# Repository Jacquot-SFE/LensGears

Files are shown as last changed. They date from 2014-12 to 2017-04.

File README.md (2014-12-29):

Laser Cut Lens Gears
==================

*NOTE: all of this work is preliminary.  Nothing here has been completed or tested.*

Resources for laser cut lens gears, starting with .8 pitch, but the sky is the limits. 

### Inkscape notes

There's a gear generator in *extensions->render->gear*.
The magic number for circular pitch is 8.835 px. (see notebook on 3/24/2014).

If you were really on top of things, you'd generate a path that traces around the outside of gear, so that the laser kerf skirted the outer edge of the gear.

Repository Contents
-------------------
* **/DesignFiles** - SVG files for the gears.  
* **/Notes** - Other relevant information.

License Information
-------------------

All contents of this repository are released under [Creative Commons Share-alike 3.0](http://creativecommons.org/licenses/by-sa/3.0/).

Author: Byron Jacquot@ SparkFun Electonics

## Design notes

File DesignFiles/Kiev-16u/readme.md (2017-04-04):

Kiev 16u Lenses
--

If you're shooting with a Blackmagic Pocket camera, you've probably heard about the lenses from the Kiev 16U, a Russian (well, Ukranian...when the cameras were made, Ukraine was part of the USSR) 16MM camera.  They come with a 3-slot turret, loaded with 3 prime lenses.

Unlike Bolex H16's, where the turret may be loaded with any number of lenses, Kiev 16Us all come with the same set of 3:

* MIR-11M 12mm/2
* VEGA-7-1M 20mm/2
* Tair-41M 50mm/2

A little googling will lead you to a bunch of reviews and test footage.  The 12mm is a touch dark in the corners.  The 50mm is a really nice lens (though on a 16mm frame, 50mm is telephoto), with a many-bladed iris, with a nearly round opening, for nice, circular bokeh.

The most likely source for these lenses is EBay.

You'll also need an MFT adapter.  They're machined by RAFCamera, and run about $50.  I bought my set of lenses from him, including the adataper.  Shipped from Belarus in about a week.

If you're shopping, a couple things to note:

* The "-M" suffix is for the Kiev 16u lenses.  The same lenses are also around in the Krasnogorsk Bayonet mount, taking a completely different adapter, and having F/2.2 apertures.  Look carefully for the threads in the pictures - they're usually kinda brassy 
   
## Gears

The files here were done for my lenses.  They may need adjustment for your own lenses.

Apparently these were in production for a long time, and there are some differences over their lifetime.  My lenses are "Zebra" style, with exposed, shiny aluminum rectangles on the aperture and focus rings.  I've also seen some all black versions, usually coming from Poland.

The OD of each gear is the same: 2.564"

The ID I measures on each focus ring:

* 12mm: 44.3mm 
* 20mm: 44.44mm
* 50mm #1: 46 (+/- 0.1)  not entirely round?  45.9 to 46.05
* 50mm #2: 46 (+/- 0.1)  not entirely round?  45.9 to 46.05

## Notes on cutting

First gears were cut from clear acrylic, for the 20mm.

ID set to 44.44 caused actual ID (allowing for kerf?) to be more like 44.7mm.  Adjusting downward by a bit, to 44.1mm, seems to fit better.  Same gear is fitting the 12mm and 20mm.

Cutter adjustments: Was doing 3 passes.  First 2 at 10 % speed, 100% power, 5000 Hz.  With those, the ID hole was cut, but teeth were still stuck.  3rd pass of just the teeth, raised to 25% speed, cut it nicely.

Only limited luck with black delrin yet.  Best results:
3.3mm black delrin, 20 % speed, 100% power, 500 Hz.  4 passes.
One issue is that the material warps as it heats up.  Another issue is that it wants to burn if the laser moves too slow, making the warping even worse.

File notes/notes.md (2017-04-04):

Notes On Designing Lens Gears
====

I'm using Inkscape for the lens gear design.  It has a gear generator tool that helps a bit.  It's not so helpful in a few regards, too.

* It's calibrated in pixels, 90 to the inch.  
* Not all programs agree on the pixel density, so transporting files may be problematic.  I think Corel uses 96 pix per inch.  
* The gear generator is also calibrated in pixels.

Gear generator is in Extensions->render->gear.
Set it as follows

* Teeth to fit diameter.
	* 80 teeth makes 2.5" pitch diameter
	* 100 teeth makes 3.125" pitch diameter
	* 128 teeth makes 4" PD.
* 8.835 pitch
* 20 degree pressure angle

I've been verifying some of my gear dimensions against  [Actobotics Gears](http://www.servocity.com/html/32_pitch_hub_gears__1__bore_.html).

## Gear Background

0.8 pitch is equivalent to 32 pitch.

32 pitch means 32 teeth on a 1" PD gear.  Thus 64 teeth is 2", 128 is 4"

Pitch diameter is the effective size of the gear, the average between the high and low spots of the teeth, or the size of an equivalent smooth wheel.  Outside diameter (OD) is a tiny bit larger.

## Lens Info

[mir.com.my](mir.com.my) has a bunch of information about old lenses, sometimes including mechanical drawings.  

### Specific Lenses

#### Nikon

I've mainly got Nikon/Nikkor glass, so that's what I can measure.

##### Nikkor-N 24mm f/2.8

Measures 2.5455" across widest part of focus ring (approx 64.6557 mm).

[](http://www.mir.com.my/rb/photography/companies/nikon/nikkoresources/6070nikkor/wides/24mmf28.pdf)

##### Nikkor-S 50mm f/1.4

Measures 67.10 mm across widest, fluted, part of focus ring.  That area is about 6mm deep, and there are 12 large flutes total, each mesa of the flutes has 10 little flutes.  Focus ruing moves forward by about 4mm as turned.

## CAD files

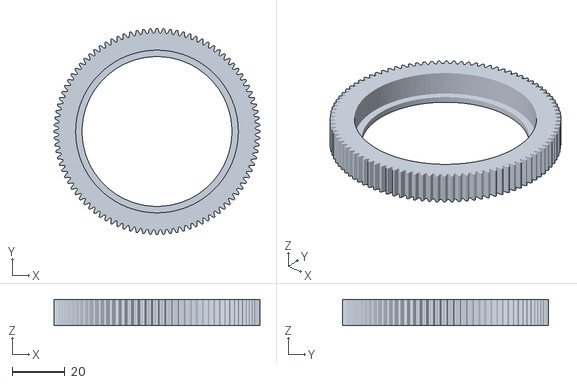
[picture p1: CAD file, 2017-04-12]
3d-design-files/35mm-E.stl
78.4 x 78.4 x 10.0

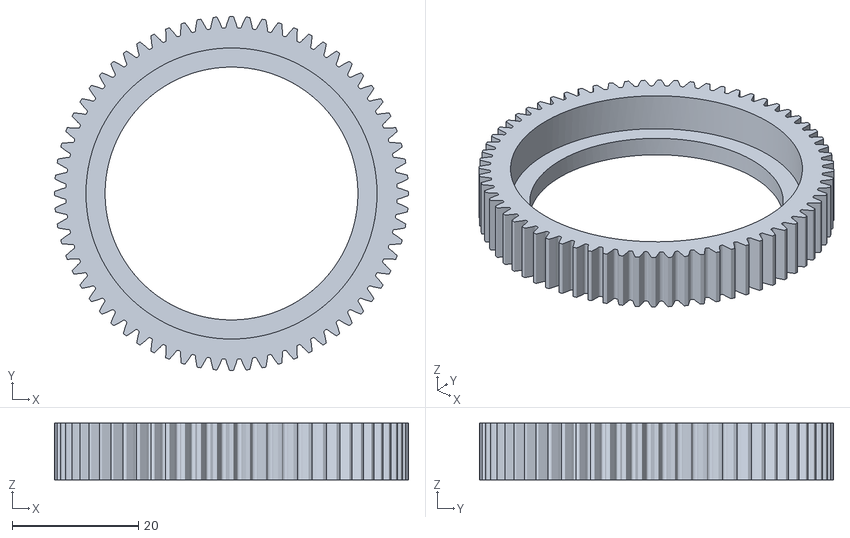
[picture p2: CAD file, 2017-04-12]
3d-design-files/50mm-tair41m-675817.stl
56.0 x 56.0 x 9.00

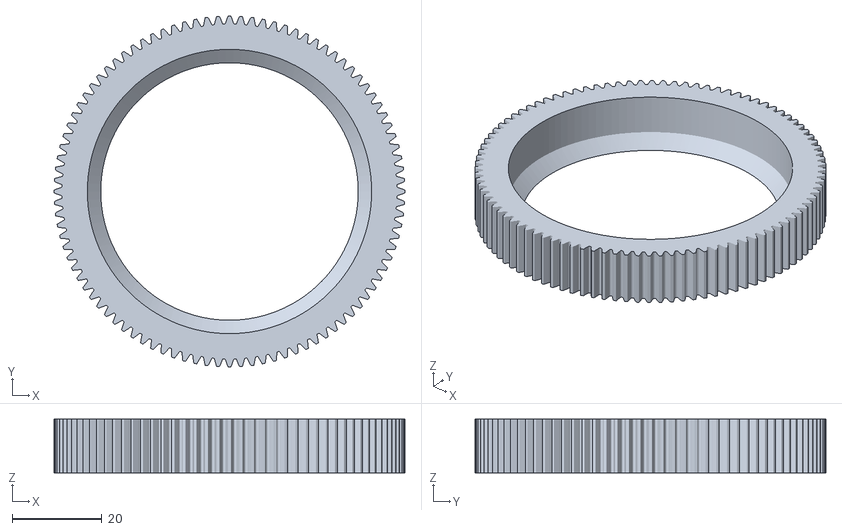
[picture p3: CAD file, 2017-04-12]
3d-design-files/28mm-rexagon.stl
78.4 x 78.4 x 12.0

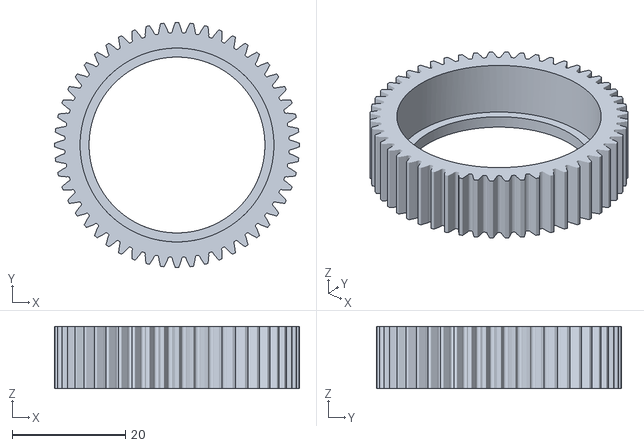
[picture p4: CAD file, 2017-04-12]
3d-design-files/izukar-16mm-take2.stl
43.2 x 43.2 x 11.0

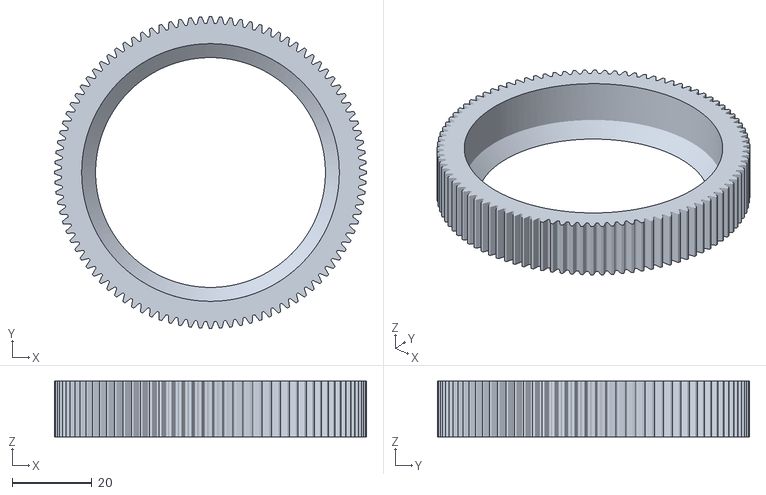
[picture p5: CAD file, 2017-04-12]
3d-design-files/24mm-N.stl
78.4 x 78.4 x 14.0

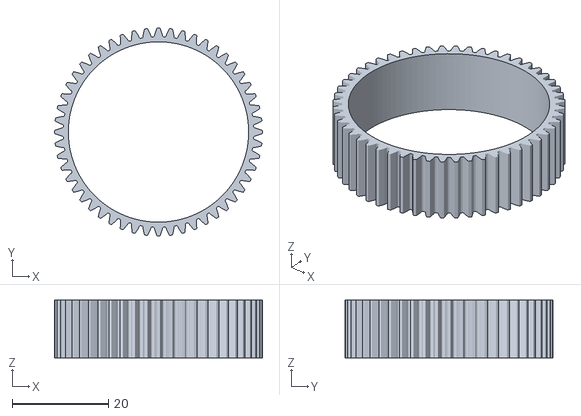
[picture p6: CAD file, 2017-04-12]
3d-design-files/izukar-16mm.stl
43.2 x 43.2 x 12.0

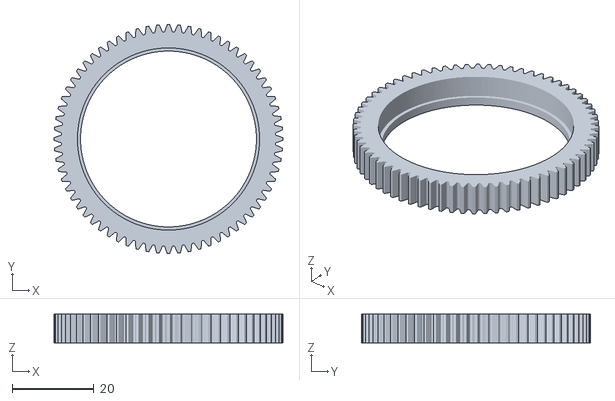
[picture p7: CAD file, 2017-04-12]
3d-design-files/12mm-mir11-701172.stl
56.0 x 56.0 x 7.00

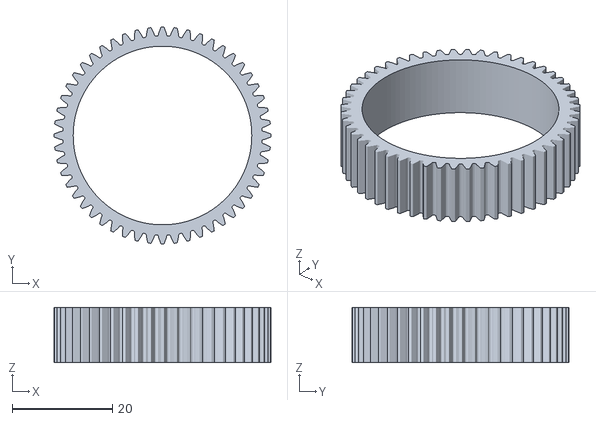
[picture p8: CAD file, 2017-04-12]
3d-design-files/fujian-25mm.stl
43.2 x 43.2 x 11.0

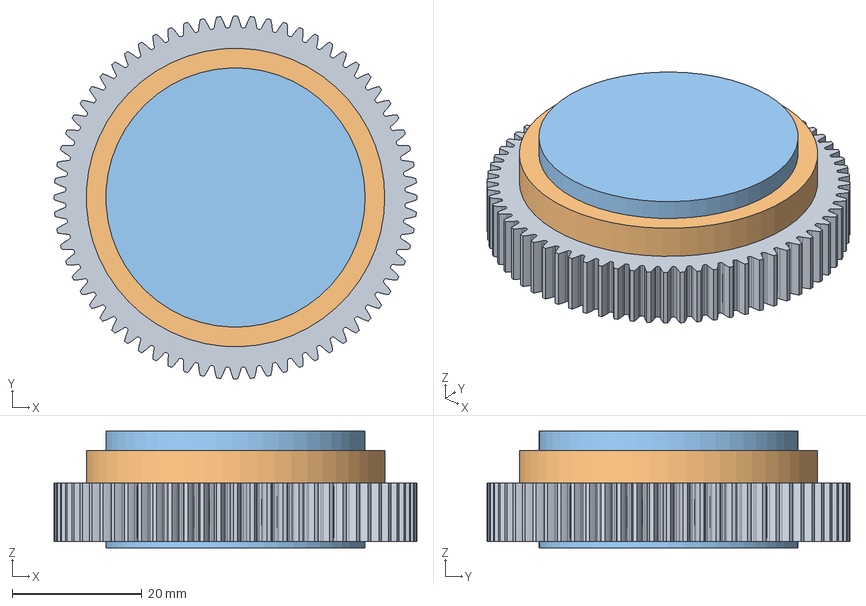
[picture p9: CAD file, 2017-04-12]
3d-design-files/parametric-model-kiev.FCStd
56.0 x 56.0 x 18.0 mm

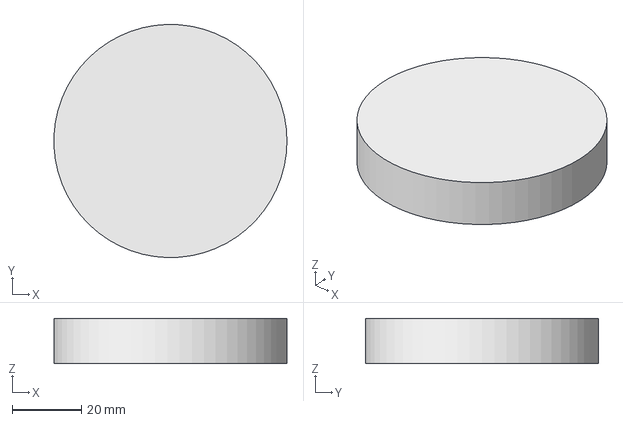
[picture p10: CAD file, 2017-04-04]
3d-design-files/parametric-model.FCStd
67.1 x 67.1 x 13.0 mm

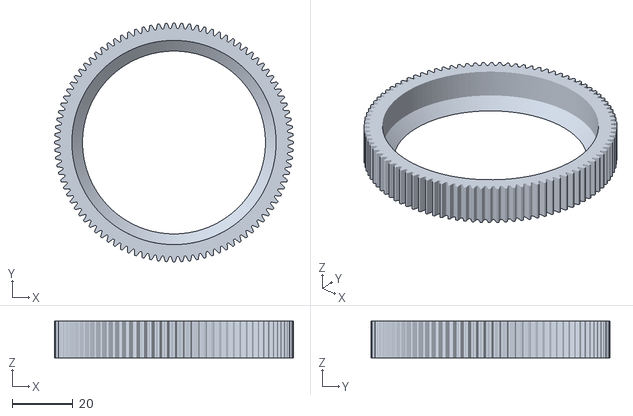
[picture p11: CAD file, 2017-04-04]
3d-design-files/50mm-S.stl
78.4 x 78.4 x 12.0

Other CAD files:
3d-design-files/20mm-beta-7-1-700594.stl
3d-design-files/p-model-rexagon.FCStd
3d-design-files/parametric-model-nikon-e.FCStd
3d-design-files/p-model-smaller.FCStd
3d-design-files/50mm-SC.stl

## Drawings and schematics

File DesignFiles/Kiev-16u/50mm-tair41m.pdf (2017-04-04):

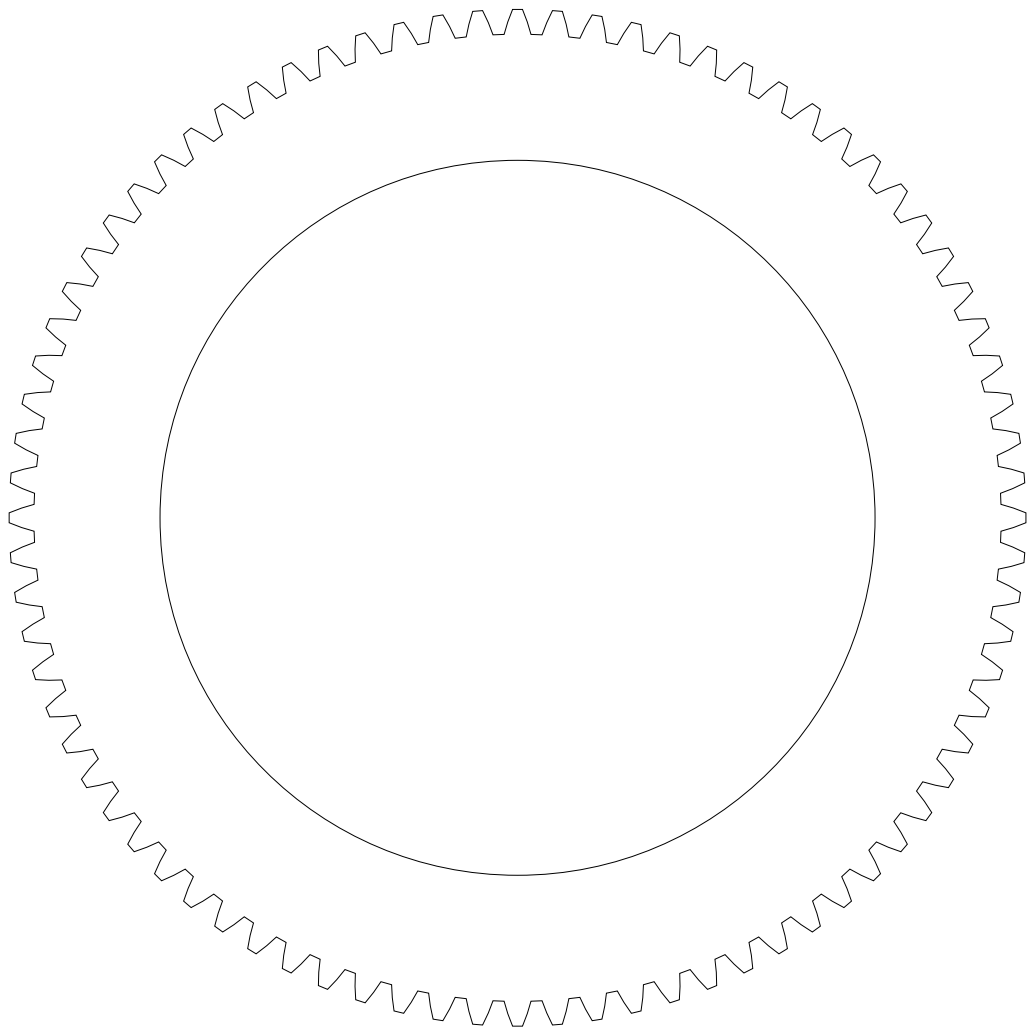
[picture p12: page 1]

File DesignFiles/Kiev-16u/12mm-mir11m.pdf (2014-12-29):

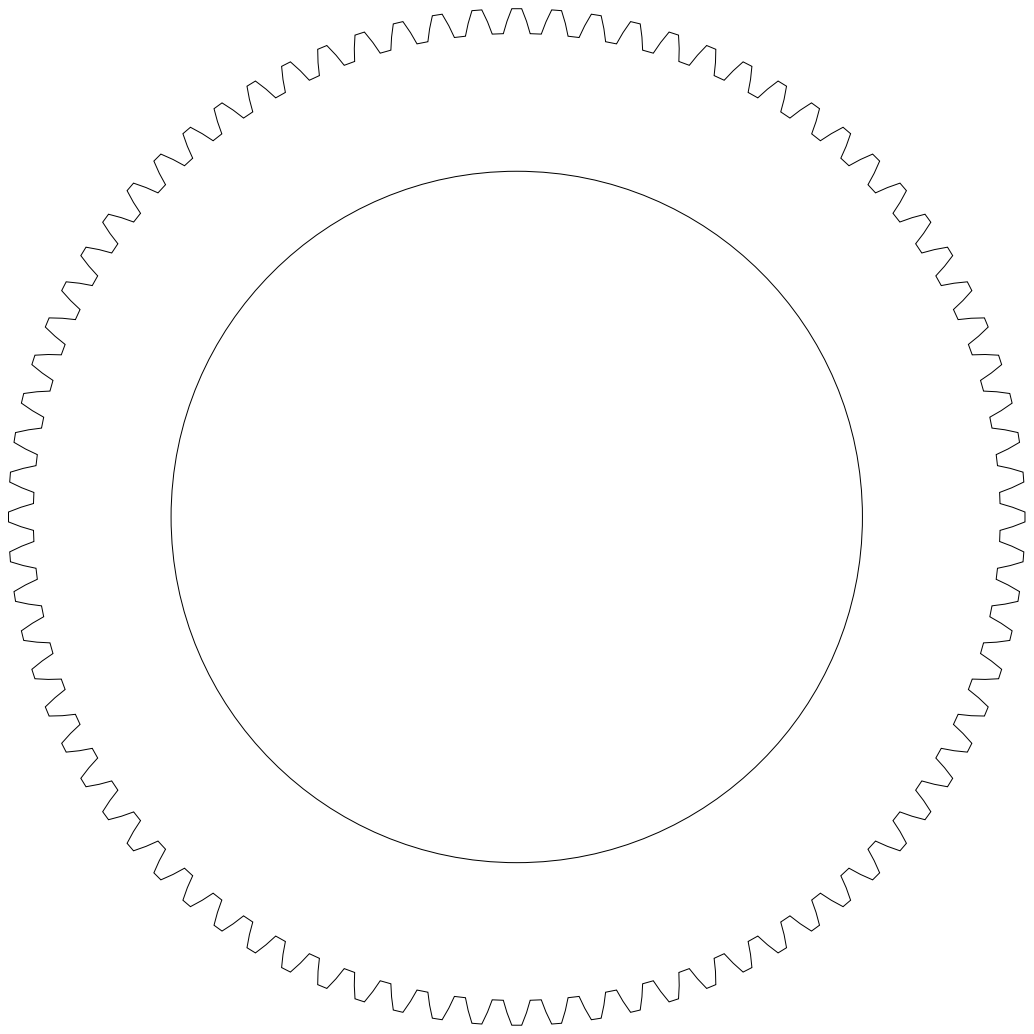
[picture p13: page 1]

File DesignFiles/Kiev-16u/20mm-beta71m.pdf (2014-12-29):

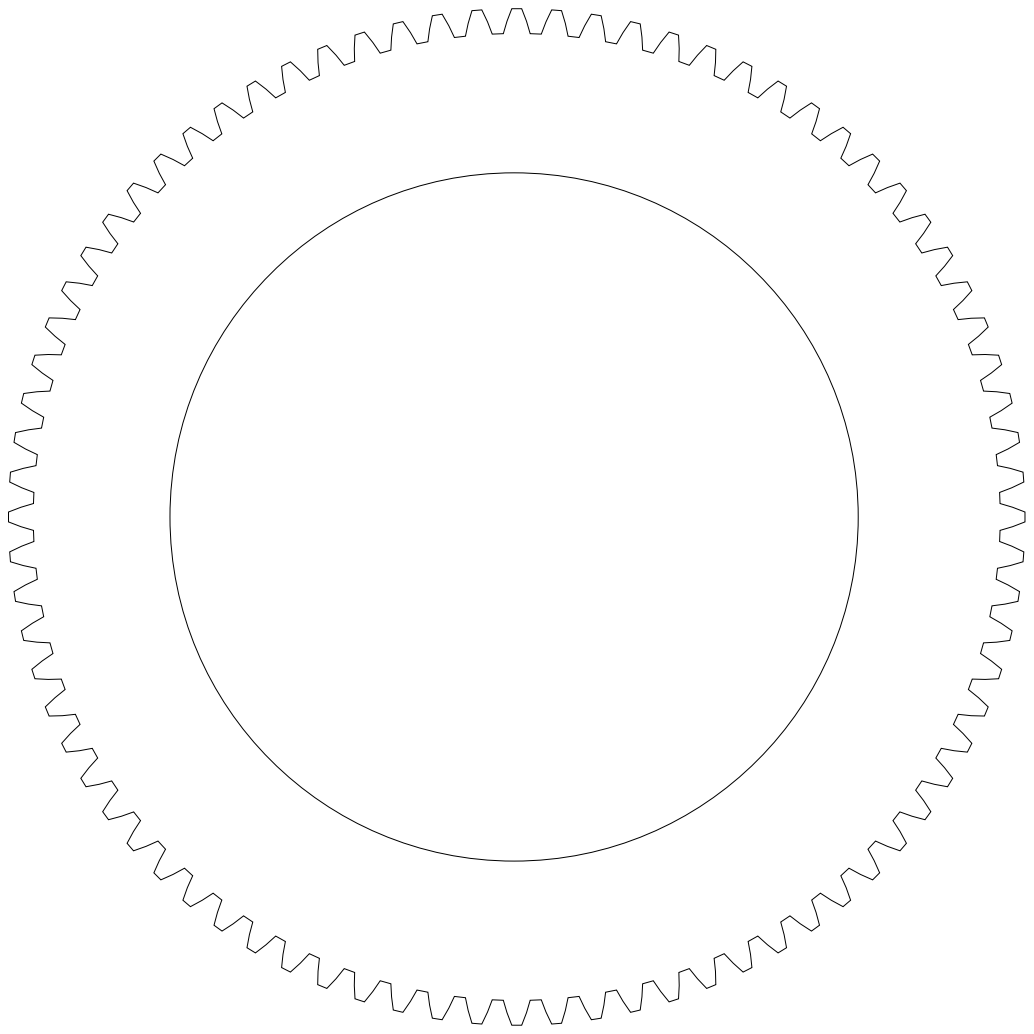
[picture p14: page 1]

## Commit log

2014-12-29 Some updates
    Added notes to readmes.
    Started on set of gears for Kiev 16U lenses. The 20mm files were
    working, on buth my 12 and 20mm lenses. The focus ring diameter varies
    quite a bit: YMMV!
    Measure twice, cut once.
2017-04-04 3D-printed gears.
    Basic parametric model generated in FreeCAD, plus a couple of STLs
    exporetd for NIkkor 50/1.4's.
    [50mm-S.stl, 50mm-SC.stl, parametric-model.FCStd]
2017-04-04 Laser cut gasket for lens-mattebox interfacing.
2017-04-12 Adding 3D cad files for many lenses.
    Drawn in FreeCAD,
    Printed on a TazMINI.
    [12mm-mir11-701172.stl, 20mm-beta-7-1-700594.stl, 24mm-N.stl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]
